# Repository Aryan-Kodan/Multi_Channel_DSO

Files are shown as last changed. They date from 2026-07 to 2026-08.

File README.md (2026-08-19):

# Multi-Channel Digital Storage Oscilloscope (DSO)

A custom **Multi-Channel Digital Storage Oscilloscope (DSO)** designed using the **STM32F103C8T6** microcontroller. This project combines a custom analog front-end, trigger circuitry, anti-alias filtering, multi-channel acquisition architecture, and a TFT display into a compact oscilloscope platform.

The analog signal conditioning was designed and verified in **LTspice**, while the complete hardware was developed in **KiCad**, including schematic capture, PCB layout, and 3D visualization.

---

# Features

- Multi-channel analog acquisition architecture
- Custom analog front-end
- Input over-voltage protection
- Adjustable gain stage
- DC offset stage
- Hardware trigger comparator
- RC anti-alias filter
- STM32F103 ADC interface
- TFT display interface
- SWD programming and debugging
- Two-layer PCB
- LTspice verified analog stages

---

# Hardware Specifications

| Parameter | Specification |
|---|---|
| MCU | STM32F103C8T6 |
| ADC | 12-bit Internal ADC |
| Channels | Multi-Channel Architecture |
| Input Protection | TVS + Schottky Clamp |
| Trigger | Hardware Comparator |
| Anti-Alias Filter | RC Low Pass |
| Display | EA_eDIPTFT32-A TFT |
| Interface | I²C |
| PCB | 2-Layer |

---

# Repository Structure

```
Multi-Channel-DSO/
│
├── BOM/
│   └── DSO.xlsx
│
├── images/
│   ├── KiCad/
│   │   ├── PCB.png
│   │   ├── PCB_3D.png
│   │   ├── PCB_3D_through.png
│   │   ├── Schematic.png
│   ├── LTspice/
│   │   ├── Final_output.png
│   │   ├── Input_waveform.png
│   │   ├── Gain_waveform.png
│   │   ├── offset_waveform.png
│   │   └── Spice_Schematic.png
│
├── KiCad/
│   ├── DSO.kicad_pro
│   ├── DSO.kicad_sch
│   └── DSO.kicad_pcb
│
├── LTspice/
│   └── Osc_front.asc
│
└── README.md
```

---

# System Architecture

```
                Analog Input
                     │
                     ▼
             Input Protection
          (TVS + Clamp Diodes)
                     │
                     ▼
             Buffer Amplifier
                     │
                     ▼
           Programmable Gain Stage
                     │
                     ▼
              DC Offset Stage
                     │
                     ▼
           Trigger Comparator
                     │
                     ├────────► STM32 Trigger Input
                     │
                     ▼
            RC Anti-Alias Filter
                     │
                     ▼
              STM32 ADC + DMA
                     │
                     ▼
            Waveform Processing
                     │
                     ▼
                TFT Display
```

---

# Analog Signal Chain

The complete analog front-end consists of:

- Input protection
- Voltage scaling
- Buffer amplifier
- Gain amplifier
- DC offset stage
- Trigger comparator
- RC anti-alias filter
- ADC interface

The design conditions incoming analog signals into the STM32 ADC input range while maintaining waveform integrity.

---

# LTspice Simulation

The complete analog signal chain was verified before PCB implementation.

Simulation stages include:

- Input waveform
- Gain stage response
- Offset stage response
- Final conditioned output
- Complete analog schematic

---

# PCB Design

The PCB was designed using **KiCad** with emphasis on:

- Compact component placement
- Analog and digital section separation
- Ground plane implementation
- Short analog signal routing
- Decoupling capacitor placement
- SWD programming interface
- TFT display interface

---

# Development Workflow

- Analog front-end design
- LTspice verification
- Schematic capture
- PCB layout
- 3D PCB visualization
- BOM generation
- Embedded firmware development *(in progress)*
- Hardware validation *(planned)*

---

# Software Used

- KiCad 9
- LTspice
- Git
- GitHub

---

# Future Improvements

- Dual simultaneous ADC acquisition
- External high-speed ADC
- DMA circular buffer implementation
- Auto trigger mode
- Single-shot trigger
- FFT spectrum analyzer
- USB waveform streaming
- SD card waveform storage
- Automatic measurements
- Cursor functions
- Frequency and duty-cycle measurement
- Rotary encoder user interface

---

# Author

**Aryan Kodan**

Electronics Engineering | Embedded Systems | PCB Design | Analog Circuit Design | VLSI

GitHub: https://github.com/Aryan-Kodan

---

# License

This project is released under the MIT License.

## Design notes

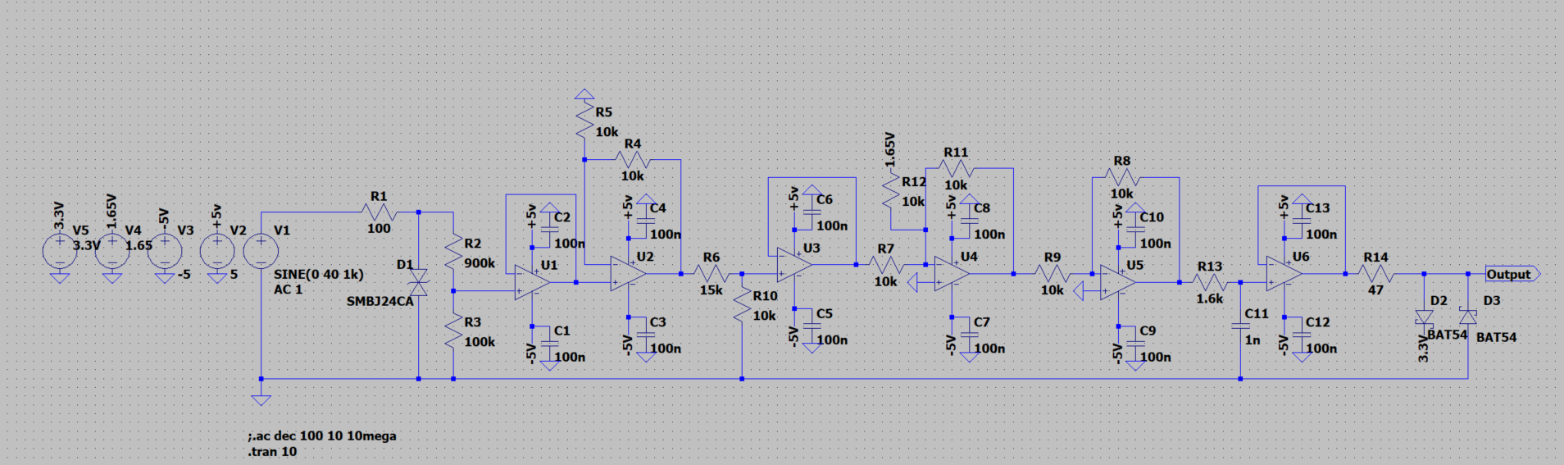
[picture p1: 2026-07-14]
images/LTspice/Spice_Schematic.png

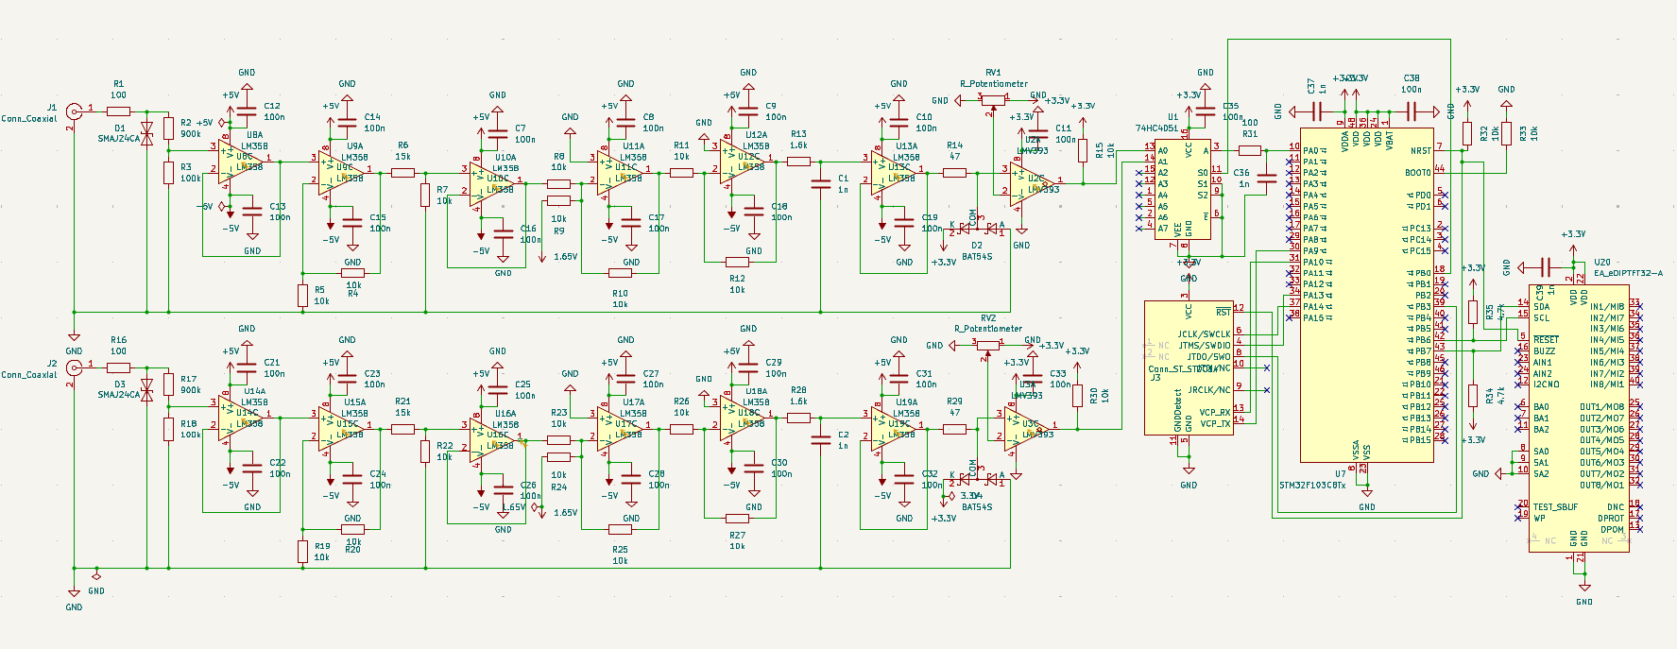
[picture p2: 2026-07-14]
images/KiCad/Schematic.png

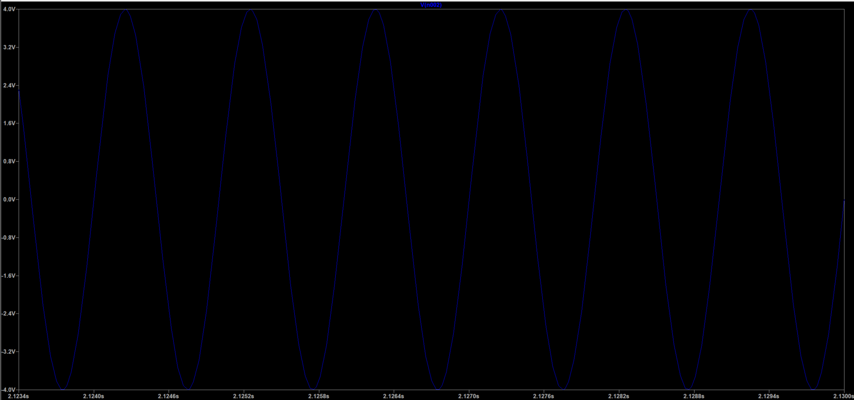
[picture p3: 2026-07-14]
images/LTspice/Gain_waveform.png

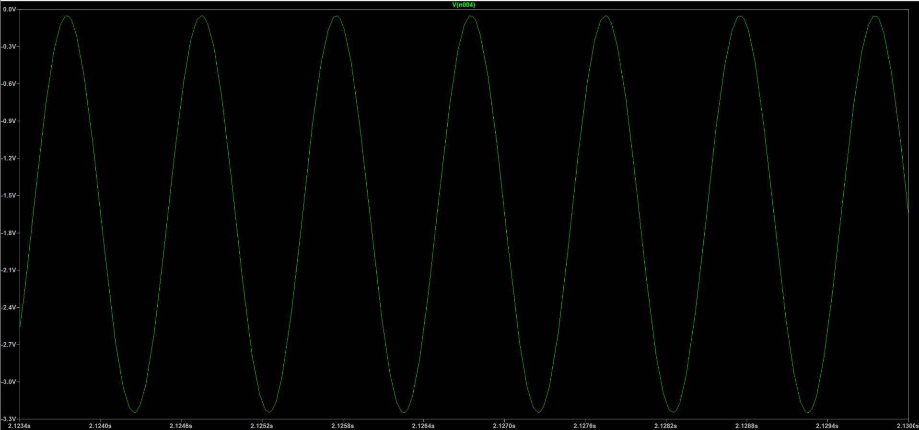
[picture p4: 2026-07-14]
images/LTspice/offset_waveform.png

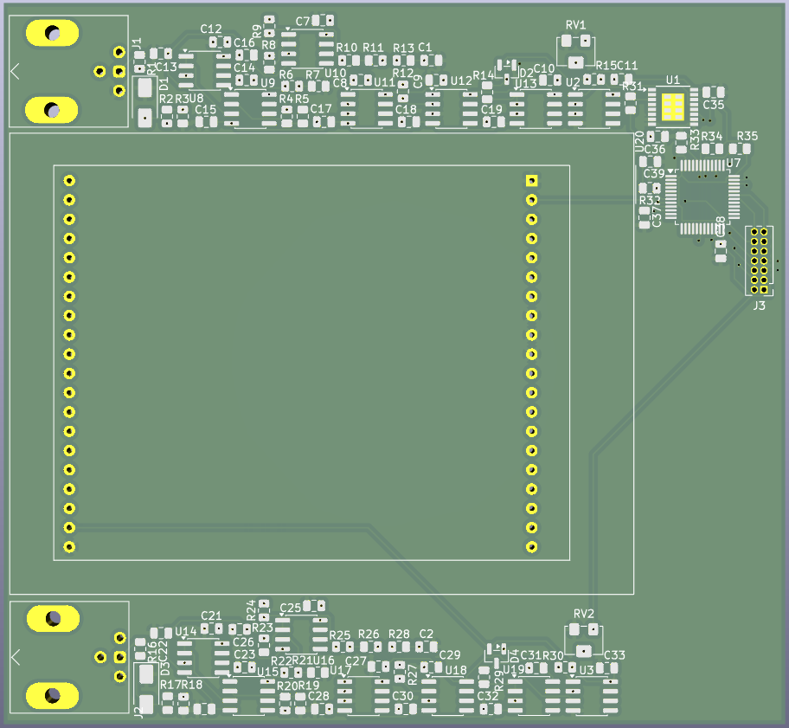
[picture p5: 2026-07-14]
images/KiCad/PCB_3D_through.png

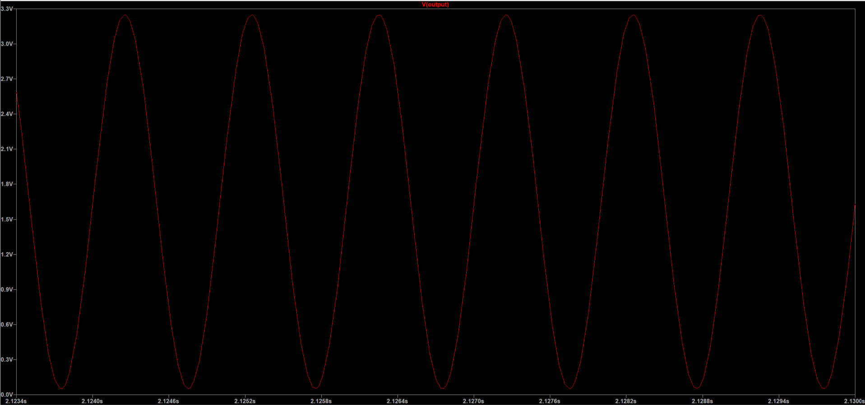
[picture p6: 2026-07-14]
images/LTspice/Final_output.png

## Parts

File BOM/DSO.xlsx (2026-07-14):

Reference | Qty | Value | DNP | Exclude from BOM | Exclude from Board | Footprint | Datasheet
C1,C2,C36,C37,C39 | 5 | 1n |  |  |  | Capacitor_SMD:C_0805_2012Metric
C7,C8,C9,C10,C11,C12,C13,C14,C15,C16,C17,C18,C19,C21,C22,C23,C24,C25,C26,C27,C28,C29,C30,C31,C32,C33,C35,C38 | 28 | 100n |  |  |  | Capacitor_SMD:C_0805_2012Metric
D1,D3 | 2 | SMAJ24CA |  |  |  | Diode_SMD:D_SMA | https://www.littelfuse.com/media?itemid=75e32973-b177-4ee3-a0ff-cedaf1abdb93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
D2,D4 | 2 | BAT54S |  |  |  | Package_TO_SOT_SMD:SOT-23 | https://www.diodes.com/assets/Datasheets/ds11005.pdf
J1,J2 | 2 | Conn_Coaxial |  |  |  | Connector_Coaxial:BNC_Amphenol_031-6575_Horizontal
J3 | 1 | Conn_ST_STDC14 |  |  |  | Connector_PinHeader_1.27mm:PinHeader_2x07_P1.27mm_Vertical | https://www.st.com/content/ccc/resource/technical/document/user_manual/group1/99/49/91/b6/b2/3a/46/e5/DM00526767/files/DM00526767.pdf/jcr:content/translations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
R1,R16,R31 | 3 | 100 |  |  |  | Resistor_SMD:R_0805_2012Metric
R2,R17 | 2 | 900k |  |  |  | Resistor_SMD:R_0805_2012Metric
R3,R18 | 2 | 100k |  |  |  | Resistor_SMD:R_0805_2012Metric
R4,R5,R7,R8,R9,R10,R11,R12,R15,R19,R20,R22,R23,R24,R25,R26,R27,R30,R32,R33 | 20 | 10k |  |  |  | Resistor_SMD:R_0805_2012Metric
R6,R21 | 2 | 15k |  |  |  | Resistor_SMD:R_0805_2012Metric
R13,R28 | 2 | 1.6k |  |  |  | Resistor_SMD:R_0805_2012Metric
R14,R29 | 2 | 47 |  |  |  | Resistor_SMD:R_0805_2012Metric
R34,R35 | 2 | 4.7k |  |  |  | Resistor_SMD:R_0805_2012Metric
RV1,RV2 | 2 | R_Potentiometer |  |  |  | Potentiometer_SMD:Potentiometer_Bourns_3214W_Vertical
U1 | 1 | 74HC4051 |  |  |  | Package_SO:TSSOP-16-1EP_4.4x5mm_P0.65mm | http://www.ti.com/lit/ds/symlink/cd74hc4051.pdf
U2,U3 | 2 | LMV393 |  |  |  | Package_SO:SOIC-8_3.9x4.9mm_P1.27mm | http://www.ti.com/lit/ds/symlink/lmv331.pdf
U7 | 1 | STM32F103C8Tx |  |  |  | Package_QFP:LQFP-48_7x7mm_P0.5mm | https://www.st.com/resource/en/datasheet/stm32f103c8.pdf
U8,U9,U10,U11,U12,U13,U14,U15,U16,U17,U18,U19 | 12 | LM358 |  |  |  | Package_SO:SOIC-8_3.9x4.9mm_P1.27mm | http://www.ti.com/lit/ds/symlink/lm2904-n.pdf
U20 | 1 | EA_eDIPTFT32-A |  |  |  | Display:EA_eDIPTFT32-XXX | http://www.lcd-module.com/fileadmin/eng/pdf/grafik/ediptft43-ae.pdf

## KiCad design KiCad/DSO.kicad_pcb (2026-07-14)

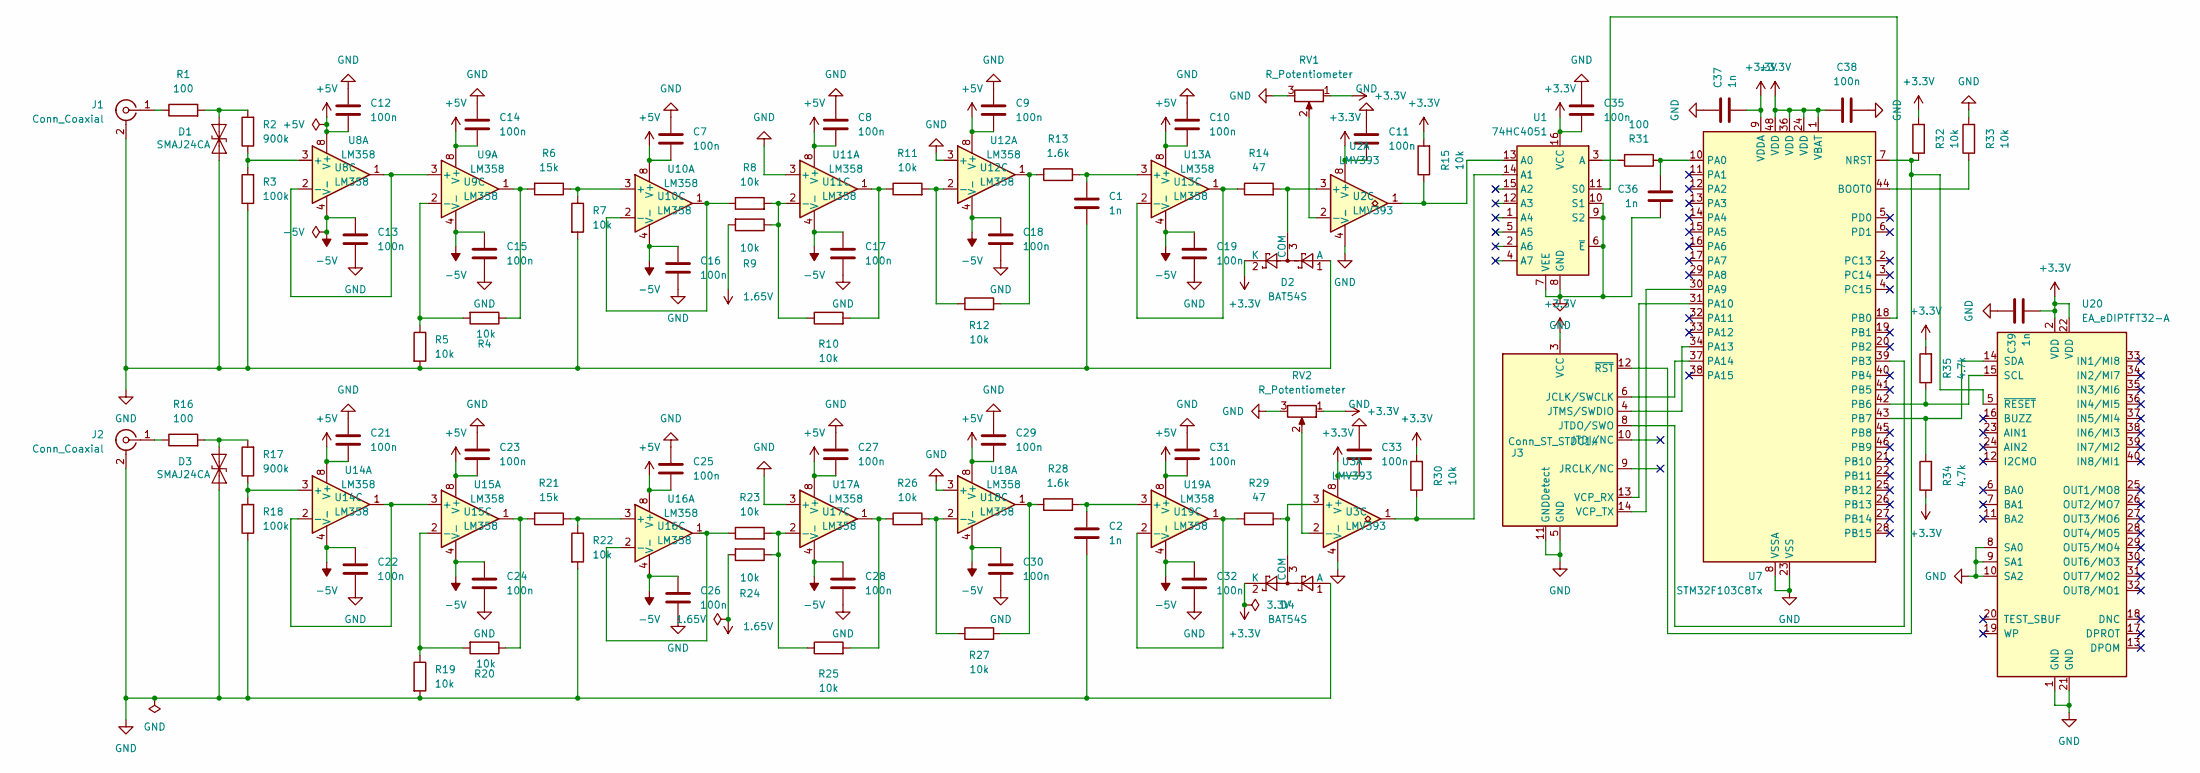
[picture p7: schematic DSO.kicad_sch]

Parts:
C1, C2, C36, C37, C39: 1n; C_0805_2012Metric
C7, C8, C9, C10, C11, C12, C13, C14, C15, C16, C17, C18, C19, C21, C22, C23, C24, C25, C26, C27, C28, C29, C30, C31, C32, C33, C35, C38: 100n; C_0805_2012Metric
D1, D3: SMAJ24CA; D_SMA
D2, D4: BAT54S; SOT-23
J1, J2: Conn_Coaxial; BNC_Amphenol_031-6575_Horizontal
J3: Conn_ST_STDC14; PinHeader_2x07_P1.27mm_Vertical
R1, R16, R31: 100; R_0805_2012Metric
R2, R17: 900k; R_0805_2012Metric
R3, R18: 100k; R_0805_2012Metric
R4, R5, R7, R8, R9, R10, R11, R12, R15, R19, R20, R22, R23, R24, R25, R26, R27, R30, R32, R33: 10k; R_0805_2012Metric
R6, R21: 15k; R_0805_2012Metric
R13, R28: 1.6k; R_0805_2012Metric
R14, R29: 47; R_0805_2012Metric
R34, R35: 4.7k; R_0805_2012Metric
RV1, RV2: R_Potentiometer; Potentiometer_Bourns_3214W_Vertical
U1: 74HC4051; TSSOP-16-1EP_4.4x5mm_P0.65mm
U2, U3: LMV393; SOIC-8_3.9x4.9mm_P1.27mm
U7: STM32F103C8Tx; LQFP-48_7x7mm_P0.5mm
U8, U9, U10, U11, U12, U13, U14, U15, U16, U17, U18, U19: LM358; SOIC-8_3.9x4.9mm_P1.27mm
U20: EA_eDIPTFT32-A; EA_eDIPTFT32-XXX

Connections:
1.65V: R9.2, R24.2
+3.3V: C11.2, C33.2, C35.2, C37.2, C38.2, C39.2, D2.2 (K), D4.2 (K), J3.3 (VCC), R15.2, R30.2, R32.2, R34.1, R35.2, RV1.1, RV2.1, U1.16 (VCC), U2.8 (V+), U3.8 (V+), U7.1 (VBAT), U7.9 (VDDA), U7.24 (VDD), U7.36 (VDD), U7.48 (VDD), U20.2 (VDD), U20.22 (VDD)
+5V: C7.2, C8.2, C9.2, C10.2, C12.2, C14.2, C21.2, C23.2, C25.2, C27.2, C29.2, C31.2, U8.8 (V+), U9.8 (V+), U10.8 (V+), U11.8 (V+), U12.8 (V+), U13.8 (V+), U14.8 (V+), U15.8 (V+), U16.8 (V+), U17.8 (V+), U18.8 (V+), U19.8 (V+)
-5V: C13.1, C15.1, C16.1, C17.1, C18.1, C19.1, C22.1, C24.1, C26.1, C28.1, C30.1, C32.1, U8.4 (V-), U9.4 (V-), U10.4 (V-), U11.4 (V-), U12.4 (V-), U13.4 (V-), U14.4 (V-), U15.4 (V-), U16.4 (V-), U17.4 (V-), U18.4 (V-), U19.4 (V-)
GND: C1.2, C2.2, C7.1, C8.1, C9.1, C10.1, C11.1, C12.1, C13.2, C14.1, C15.2, C16.2, C17.2, C18.2, C19.2, C21.1, C22.2, C23.1, C24.2, C25.1, C26.2, C27.1, C28.2, C29.1, C30.2, C31.1, C32.2, C33.1, C35.1, C36.2, C37.1, C38.1, C39.1, D1.1 (A1), D2.1 (A), D3.1 (A1), D4.1 (A), J1.2 (Ext), J2.2 (Ext), J3.5 (GND), J3.7 (GND), J3.11 (GNDDetect), R3.1, R5.2, R7.2, R18.1, R19.2, R22.2, R33.2, RV1.3, RV2.3, U1.6 (~E), U1.7 (VEE), U1.8 (GND), U1.9 (S2), U1.10 (S1), U2.4 (V-), U3.4 (V-), U7.8 (VSSA), U7.23 (VSS), U7.35 (VSS), U7.47 (VSS), U11.3 (+), U12.3 (+), U17.3 (+), U18.3 (+), U20.1 (GND), U20.8 (SA0), U20.9 (SA1), U20.10 (SA2), U20.21 (GND)
unnamed: D1.2 (A2), R1.2, R2.2
unnamed: D2.3 (COM), R14.2, U2.3 (+)
unnamed: D3.2 (A2), R16.2, R17.2
unnamed: D4.3 (COM), R29.2, U3.3 (+)
unnamed: J1.1 (In), R1.1
unnamed: J2.1 (In), R16.1
unnamed: J3.6 (JCLK/SWCLK), U7.37 (PA14)
unnamed: J3.8 (JTDO/SWO), U7.39 (PB3)
unnamed: J3.4 (JTMS/SWDIO), U7.34 (PA13)
unnamed: J3.13 (VCP_RX), U7.31 (PA10)
unnamed: J3.14 (VCP_TX), U7.30 (PA9)
unnamed: J3.12 (~RST), R32.1, U7.7 (NRST), U20.5 (~RESET)
unnamed: R4.1, R6.2, U9.1
unnamed: R10.2, R11.1, U11.1
unnamed: R12.2, R13.1, U12.1
unnamed: R20.1, R21.2, U15.1
unnamed: R25.2, R26.1, U17.1
unnamed: R27.2, R28.1, U18.1
unnamed: R15.1, U1.13 (A0), U2.1
unnamed: R30.1, U1.14 (A1), U3.1
unnamed: R31.2, U1.3 (A)
unnamed: U1.11 (S0), U7.18 (PB0)
unnamed: RV1.2, U2.2 (-)
unnamed: RV2.2, U3.2 (-)
unnamed: R33.1, U7.44 (BOOT0)
unnamed: C36.1, R31.1, U7.10 (PA0)
unnamed: R2.1, R3.2, U8.3 (+)
unnamed: U8.1, U8.2 (-), U9.3 (+)
unnamed: R4.2, R5.1, U9.2 (-)
unnamed: R6.1, R7.1, U10.3 (+)
unnamed: R8.1, U10.1, U10.2 (-)
unnamed: R8.2, R9.1, R10.1, U11.2 (-)
unnamed: R11.2, R12.1, U12.2 (-)
unnamed: C1.1, R13.2, U13.3 (+)
unnamed: R14.1, U13.1, U13.2 (-)
unnamed: R17.1, R18.2, U14.3 (+)
unnamed: U14.1, U14.2 (-), U15.3 (+)
unnamed: R19.1, R20.2, U15.2 (-)
unnamed: R21.1, R22.1, U16.3 (+)
unnamed: R23.1, U16.1, U16.2 (-)
unnamed: R23.2, R24.1, R25.1, U17.2 (-)
unnamed: R26.2, R27.1, U18.2 (-)
unnamed: C2.1, R28.2, U19.3 (+)
unnamed: R29.1, U19.1, U19.2 (-)
unnamed: R35.1, U7.42 (PB6), U20.15 (SCL)
unnamed: R34.2, U7.43 (PB7), U20.14 (SDA)

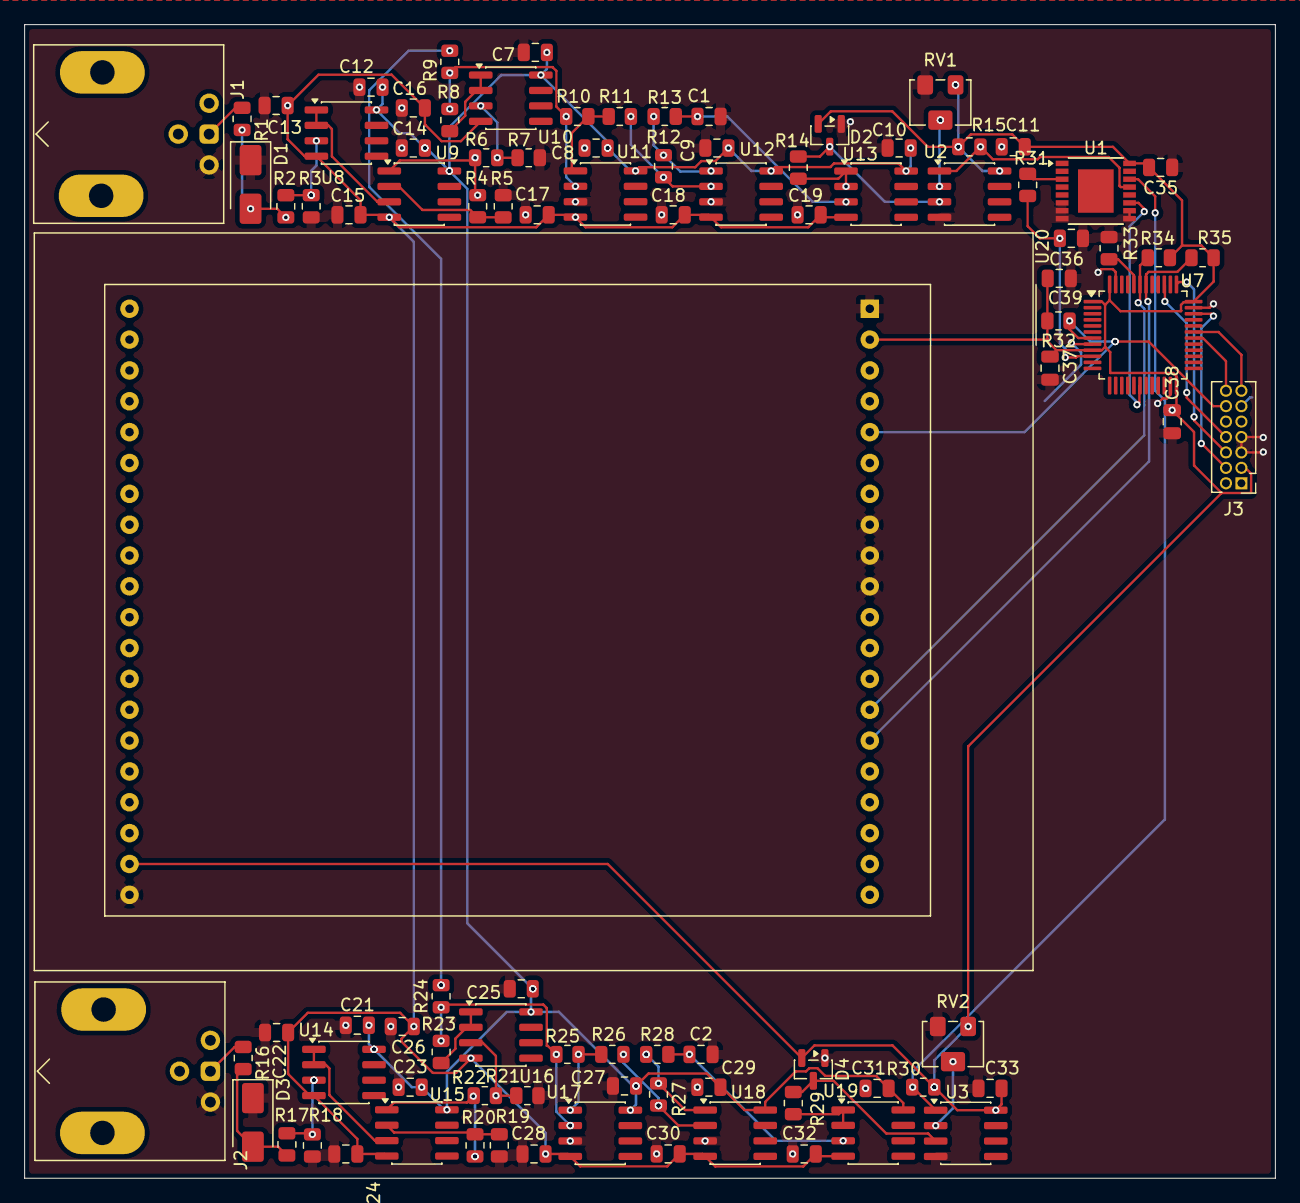
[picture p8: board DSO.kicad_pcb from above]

Board: 2 copper layers, 103.0 x 95.0 mm, 94 parts (0 on the bottom side), 51 nets.
